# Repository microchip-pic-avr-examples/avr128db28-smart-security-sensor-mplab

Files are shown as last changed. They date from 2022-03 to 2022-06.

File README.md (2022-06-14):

<!-- Please do not change this logo with link -->

MCHP (https://www.microchip.com)

# Window Security Sensor with an AVR&reg; DB Microcontroller,  MLX90632 and MLX90392

The objective of this application is to create a window security sensor with room temperature monitoring for a compact smart home solution. The AVR128DB28 microcontroller was selected for this application in order to use [Multi-Voltage I/O (MVIO) peripheral](#) to communicate with the sensors. To implement this solution, an [MLX90632](https://www.melexis.com/en/product/MLX90632) and an [MLX90392 sensor](https://www.melexis.com/en/product/MLX90392) were used.

This application was co-developed with Melexis, a global supplier of microelectronic semiconductor solutions.

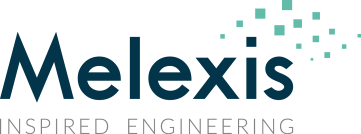
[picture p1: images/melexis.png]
Melexis Logo (https://www.melexis.com/)


## Related Documentation
- [MLX90632 (FIR Thermometer) Homepage](https://www.melexis.com/en/product/MLX90632/Miniature-SMD-Infrared-Thermometer-IC)
  - [MLX90632 Reference Software Library (from Melexis)](https://github.com/melexis/mlx90632-library)
- [MLX90392 (3D Magnetometer) Homepage](https://www.melexis.com/en/product/MLX90392/3D-Magnetometer-micro-power-and-cost-conscious)
- [MVIO Peripheral Homepage](https://www.microchip.com/en-us/products/microcontrollers-and-microprocessors/8-bit-mcus/core-independent-and-analog-peripherals/system-flexibility/mvio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)
- [AVR128DB28 Device Homepage](https://www.microchip.com/wwwproducts/en/AVR128DB28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)

## Software Used

- [MPLAB&reg; X IDE v6.0.0 or newer](https://www.microchip.com/en-us/tools-resources/develop/mplab-x-ide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)
- [MPLAB XC8 v2.36 or newer](https://www.microchip.com/en-us/tools-resources/develop/mplab-xc-compilers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)
- [AVR-Dx_DFP v2.0.151](https://packs.download.microchip.com/)  
- Bluetooth&reg; Smart Data App by Microchip
  - [For iOS](https://apps.apple.com/us/app/bluetooth-smart-data/id1004033562)
  - [For Android](https://play.google.com/store/apps/details?id=com.microchip.bluetooth.data&hl=en_US&gl=US)

## Hardware Used

Please consult the Bill of Materials (BOM) in the PCB documentation.

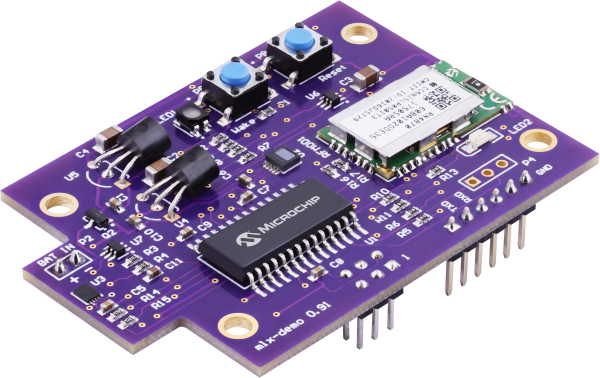
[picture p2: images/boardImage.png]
Board Image


## New in Version 1.1

- Added Range Check
  - Range check allows the demo to also verify the range of X, Y, and Z magnitudes to ensure the magnet is in the correct place. This feature increases the sensitivity of the monitoring. This feature can be disabled in *windowAlarm_config.h* by commenting out `MAGNETOMETER_RANGE_CHECK`.
- Improved Power Efficiency
  - Peripherals are switched off when not needed.
  - Turned off a few missed I/O buffers.
  - Disabled CMP Interrupt in low-power mode if Temperature Monitoring in Sleep is disabled.
  - Magnetometer is now tied to the timing of the microcontroller, which guarantees no missed samples and allows the magnetometer to enter the idle state between cycles.
  - Increased PIT cycle time to better match with magnetometer timing. *This increases the alarm response time of the demo by a small amount.*
- EEPROM Improvements
  - Byte 0 of the EEPROM is now a version ID. Upgrading to a new version of the demo should now automatically reset the EEPROM to defaults. (Note: It is still recommended to fully erase the EEPROM before upgrading.)
  - Added max and min for X, Y, and Z vectors for range check.
  - Using the command `RESET` will now clear the marker for the alarm calibration, forcing a recalibration to occur, **even if power cycled**.
  - Added `EEPROM.md` as documentation about the structure of the EEPROM.
- Bug Fixes

## Table of Contents

- [Estimated Power Consumption](#estimated-power-consumption)
  - [Active Modes (Paired)](#active-modes--paired-)
  - [Slow (30s) Update Rate](#slow--30s--update-rate)
  - [Normal (15s) Update Rate](#normal--15s--update-rate)
  - [Fast (3s) Update Rate](#fast--3s--update-rate)
- [Window Alarm Sensing](#window-alarm-sensing)
  - [The Advantage of a Magnetometer](#the-advantage-of-a-magnetometer)
  - [Calibrating the Magnetometer](#calibrating-the-magnetometer)
    - [Step 1 - Zero Calibration](#step-1---zero-calibration)
    - [Step 2 - Data Normalization](#step-2---data-normalization)
    - [Step 3 - Threshold Set](#step-3---threshold-set)
    - [Step 4 - Return to Closed](#step-4---return-to-closed)
- [Temperature Measurements](#temperature-measurements)
  - [Timing](#timing)
  - [Constant Caching](#constant-caching)
- [Advanced Features](#advanced-features)
  - [Safe Mode](#safe-mode)
- [Operating the Demo](#operating-the-demo)
- [User Commands](#user-commands)

## Estimated Power Consumption

Important: **These values are provided for reference only.** Data collected from 1 unit on the bench. Values were rounded to the nearest &micro;A.

Values were captured with the system powered from a DC power supply at 4.5V through a calibrated precision digital multimeter (with a sampling rate of 10 ksps - 1,000,000 samples per run).

Update rates determine how often new temperature measurements are collected and how often system status reported (either via Bluetooth or the flashed LED, depending on the operating mode).

Magnetometer samples at a constant rate in all modes, except calibration mode. In calibration mode, a higher sampling rate is used.

**Note: Characterized with U7 not populated (VBAT measurement switch). This is not expected to affect power consumption significantly.**  

### Active Modes (Paired)
| Operating Mode | Average Current |
| --- | ---
| Active Mode | 3.928 mA
| Calibration Mode | 5.253 mA

Power consumption in active mode is not expected to vary significantly with update rate.

### Slow (30s) Update Rate
| Operating Mode | Average Current |
| --- | ---
| Low-Power Mode (Temp not Monitored)| 149 &micro;A
| Low-Power Mode (Temp Monitored)| 189 &micro;A

### Normal (15s) Update Rate
| Operating Mode | Average Current |
| --- | ---
| Low-Power Mode (Temp not Monitored)| 151 &micro;A
| Low-Power Mode (Temp Monitored)| 222 &micro;A

### Fast (3s) Update Rate
| Operating Mode | Average Current |
| --- | ---
| Low-Power Mode (Temp not Monitored)| 171 &micro;A
| Low-Power Mode (Temp Monitored)| 505 &micro;A

## Window Alarm Sensing

Sensor Version: MLX90392-011 (&plusmn;50 mT version)

### The Advantage of a Magnetometer

One of the most common ways to detect whether a window or door has been opened/closed by an unknown person is to use a magnetic reed switch. When a magnet is placed near the switch, the two contacts inside either open or close. An external alarm circuit can monitor each circuit to know the current state of the system.

While reed switches are simple and easy to use, they come with the drawback that they only have 2 binary states. If an external magnet is placed close to the switch, the field from the added magnet can hold the contacts in position while the window is opened.

A magnetometer avoids this problem by measuring the intensity of the magnetic field. If the intensity changes beyond a set range, then the magnetometer can detect the attempt to bypass the alarm.

### Magnet Selection and Performance

We tried using a few different magnets during development. An inexpensive off-the-shelf security sensor magnet was used during the initial prototyping without issue, but we found that when mounted a real window, it was too sensitive for long-term use. We found that using a stronger magnet significantly improved performance on the real window. (Alternatively, using the more sensitive device variant of the magnetometer may improve performance with weak magnets.)

We suspect the reason for this discrepancy is due to the increased distance between the magnet and the sensor due to mounting + the protective case.

Note: There is a finite magnetic field range that the sensor can measure. If the magnet is too strong for the sensor, the alarm will be triggered and an error code will occur during calibration.

### Calibrating the Magnetometer

Before using the magnetometer in system, it must be calibrated. Small variations in installation and position are more than enough to cause the alarm to trigger. After some internal testing, we found a 4-step calibration routine worked best.

1. Zero Calibration
2. Data Normalization
3. Threshold Set
4. Return to Closed

#### Step 1 - Zero Calibration

User Directions: *Open the window and press the button to start.*  

To zero the sensor, the microcontroller collects a set number of samples from the magnetometer with the magnet on the window in the farthest position from the sensor. After the set number of samples are acquired, the microcontroller computes the (whole number) average from the totals in each dimension and uses this as the offset.

#### Step 2 - Data Normalization

User Directions: *Please close the window and the press the button to continue.*  

The objective of the data normalization to scale each of the 3 axes to be in similar scales to each other. Due to the direction of travel, one of the axes will have a much higher scale than the others.

The calibration algorithm in this step performs a similar action to the [Zero Calibration in Step 1](#step-1---zero-calibration). However, each averaged value is used to compute the scaling factor to compress the values to a signed 8-bit number. If the value is negative, then the scaling factor will be negative.

| Input | Computed Scaling Factor | Normalized Value
| ----- | --- | ---
| 255 | 1 | 127
| -80 | -1 | 80
| -288  | -2 | 72

At the conclusion of this step, the max/min normalized values for each axis starts to be monitored.

**Note: Ideally the values would remain 7-bit, but depending on the placement of the magnetometer, it is possible for the maximum intensity to occur in a slightly different position. The program limits the maximum intensity to 127. For total magnitude, the full normalized value is used.**

#### Step 3 - Threshold Set

User Directions: *Please open the window to the desired threshold, then press the button.*  

In this step, the magnetometer is programmed to the threshold between open and closed. Unlike the reed switch, the user can set how far the window is open before triggering the alarm. Additionally, at the conclusion of this step, the program stores the highest magnitude of the field strength recorded between (the end of) step 2 and 3.

Magnitude<sup>2</sup> = X<sup>2</sup> + Y<sup>2</sup> + Z<sup>2</sup>

The maximum magnitude is used to protect against attempts to tamper with the sensor with another magnet.

When this step completes, the max/min normalized values for each axis will stop being monitored.

#### Step 4 - Return to Closed

User Directions: *Please close the window and press the button to finish.*  

This step validates the calibration while the user closes the window. If the alarm triggers during this, the calibration is considered bad and returns to step 1. If the window is closed and the alarm did not trigger, then the constants are saved to the EEPROM of the microcontroller.

## Temperature Measurements

Sensor: MLX90632

### Timing

The MLX90632 sensor takes 500ms to get one half of a sample (see sensor datasheet), and/or 1s for a full conversion. This demo only uses the full conversion timing. Due to the acquisition time delay, the microcontroller starts the temperature acquisition early to ensure the results are ready when the application prints the status.

### Constant Caching
To improve the start-up time of the application, the factory calibration constants stored on the MLX90632 are converted into the required floating point values and are stored in the microcontroller's EEPROM memory.

On startup, the microcontroller looks at the EEPROM to:

- Match the serial number of the sensor to the value in memory
- Match the XOR of the serial number words

If either of these checks fail, then the memory is considered invalid, and the constants will be reacquired and reprogrammed into EEPROM. Other constants related to the temperature sensor will also be reset.

Constant Caching can be disabled by commenting out the macro `CACHE_CONSTANTS` in **MLX90632.h**. Booting the application in safe mode will also ignore the EEPROM values.

## Advanced Features

### Safe Mode
To enter safe mode:
- Hold the "Wake" button
- Power-up the demo

In safe mode, the application ignores stored values in EEPROM and resets all user settings to the compile-time defaults. Constants for the MLX90632 (temp. sensor) will be reacquired and cached and the magnetometer will need to be recalibrated before use.

**Note: If the application is powered-off before recalibrating the magnetometer, the magnetometer will load the old calibration on the next start-up.**

## Operating the Demo

For ease of demonstrability, an [RN4870 Bluetooth module](https://www.microchip.com/en-us/product/RN4870) was used for wireless communication. In a production setting, we'd recommend switching to a different wireless communication method, like [Sub-GHz Radio](https://www.microchip.com/en-us/products/wireless-connectivity/sub-ghz).

### Pairing

Instructions, System Conditions, and other messages are sent via Bluetooth to the user's smartphone.

1. Open the Microchip Smart Data App
  1. Download links are provided in the [Software Used](#software-used) section.
2. Power-On the Demo Board.
3. Connect to the Bluetooth Device **MCHP-MLX_UXYZ**, where UXYZ is the S/N of the RN4870.
4. After connecting, a status message should appear in the app's terminal window.

### Sending Commands

Commands can be sent to the demo board to get more information or changing operating parameters / user settings.

All commands must be sent in the following format: **!\<Command,Parameter\>!**, with the ! acting as the deliminator. In cases where the parameter is not used (ex: HELP), it should be omitted.

Command Examples:  
**!HELP!** - Prints Help  
**!STU,F!** - Sets Temperature Units to Fahrenheit

Commands are not case-sensitive.

### User Command List

| User Command | Format | Example Use | Description
| --- | --- | --- | ---
| HELP | HELP | HELP | Get help with this demo. (Provides link to this document.)
| DEMO | DEMO | DEMO | Prints information about this demo and the build date/time. Also aliased as INFO.
| USER | USER | USER | Prints current user-defined settings
| CAL | CAL | CAL | Prints current calibration constants (for developers only)
| MAGRAW | MAGRAW | MAGRAW | Requests the next magnetometer result to be displayed on the screen. This usually occurs immediately after sending this command.
| VBAT  | VBAT  | VBAT | Prints current battery voltage. This function will block for 50 ms to allow the voltage divider to stabilize before measurement.
| RECAL | RECAL | RECAL | Triggers a new calibration cycle of the demo.
| STATUS | STATUS | STATUS | Prints the current system status.
| RESET | RESET | RESET | Resets the user settings to the defaults. The demo will also be reset to calibration mode.
| REBOOT | REBOOT | REBOOT | Reboots the microcontroller, but does NOT reset the settings.
| STU  | STU,<C/F/K> | STU,F | Sets the Temperature Unit (Celsius (*default*), Fahrenheit, Kelvin).
| STWH | STWH,\<TEMP\> | STWH,40.1 | Sets the High Temperature Alarm Point. Units are inherited from STU.
| STWL | STWL,\<TEMP\> | STWL,10.0 | Sets the High Temperature Alarm Point. Units are inherited from STU.
| STSR | STSR, \<FAST/NORM/SLOW\> | STSR,FAST | Sets the sampling rate of the temp sensor to 3s, 15s, or 30s intervals.
| PWDWN | PWDWN | PWDWN | Electrically disconnects the Bluetooth radio, stopping communications. Calibration must be valid and alarm is inactive to enter this state. See [Low Power Mode](#low-power-mode) for more information. Also aliased as PWRDWN.
| BTIDLEOFF | BTIDLEOFF,\<TRUE/FALSE\> | BTIDLEOFF,false | Enables (true) or disables (false) idle Bluetooth power-down. If enabled, after 30s where the system is not connected to a device, calibration is OK, and alarm is inactive, the system will auto-switch to [Low Power Mode](#low-power-mode).
| TEMPSLEEP | TEMPSLEEP,\<TRUE/FALSE\> | TEMPSLEEP, true | Enables temp monitoring while in sleep. If enabled, the system will measure the temperature via the FIR sensor. If the temperature is out of the expected ranges, the system will wake-up and restart the Bluetooth radio. **This mode will increase power consumption. It is recommended to use NORMAL or SLOW speed update rates to minimize power usage.**

### LED Status Indicator

The RGB LED on the board is used to indicate the following statuses:

Red LED - Alarm Tripped  
Green LED - Alarm Good  
Blue LED - Connected (and able to send) UART to the Smartphone  

If both Red and Green are active, the device is in calibration mode.

### Calibration Mode

To enter calibration mode, press the "Wake" button when NOT in Low Power mode or by sending the command "RECAL".

**Note: If in calibration mode and the board is powered off before completed the calibration previous calibration settings will be used. (Calibration values in progress are NOT stored in EEPROM until the cycle has finished). If the stored values are invalid, the system will request calibration on power being restored.**

### Low Power Mode

For longer battery life, the demo can be placed into Low Power Mode. In this mode, the Bluetooth radio is electrically disconnected from the power-supply. If the alarm is triggered in low power mode, the microcontroller will restart the Bluetooth module and wake-up. While in low power mode, commands from the user are not accepted. **On startup, the device does NOT start in Low Power Mode.**

To enter Low Power Mode, send the "PWDWN" command while the calibration is valid and the alarm is inactive.   
To exit Low Power Mode, press the Cal. button on the demo.

Note: Debug UART will remain active in Low Power Mode.

### Debug UART

A second UART is used on the device to print errors and technical information. A standard off-the-shelf USB-UART bridge can be connected to this pin header to view this output. Debug UART remains active in all modes, including Low Power Mode.

UART Settings:
- 115,200 Baud
- 8 bits, no parity, 1 stop bit
- Transmit Only (receiver not enabled)

## Summary

This demo has shown how MVIO can be used to interface with sensors that run at a different voltage level than the rest of the device. Special thanks again to Melexis for development assistance with this demo.

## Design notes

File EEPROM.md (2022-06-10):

# Internal EEPROM Structure and Mapping

This file is a reference for the structure of the Microcontroller's EEPROM used by the Smart Window Security Sensor.

## Example of a Functioning EEPROM

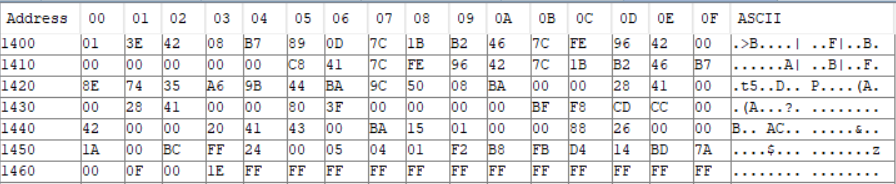
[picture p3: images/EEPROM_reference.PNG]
Reference EEPROM


## Memory Mapping

Without Angle Ranges: 0x1400 to 0x1464  
With Angle Range: 0x1400 to 0x1470

| Address | Variable Name | Type | Length | Description
| --- | --- | ---- | --- | ---
| 0x1400  | MEM_EEPROM_LAYOUT_VERSION_ID | uint8_t | 1 byte | Version ID of the EEPROM Formatting. If the EEPROM is restructured, changing the value of `EEPROM_LAYOUT_VERSION_ID` will cause a mismatch at this location, triggering safe mode on the first power-up after the update.
| 0x1401  | MEM_DEVICE_ID1 | uint16_t | 2 bytes | 1st chunk of the device ID from MLX90632. Used to verify temperature settings.
| 0x1403  | MEM_DEVICE_ID2 | uint16_t | 2 bytes | 2nd chunk of the device ID from MLX90632. Used to verify temperature settings.
| 0x1405  | MEM_DEVICE_ID3 | uint16_t | 2 bytes | 3rd chunk of the device ID from MLX90632. Used to verify temperature settings.
| 0x1407 | MEM_P_R | float | 4 bytes | Cached constant `P_R` from MLX90632.
| 0x140B | MEM_P_G | float | 4 bytes | Cached constant `P_G` from MLX90632.
| 0x140F | MEM_P_T | float | 4 bytes | Cached constant `P_T` from MLX90632.
| 0x1413 | MEM_P_O | float | 4 bytes | Cached constant `P_O` from MLX90632.
| 0x1417 | MEM_EA | float | 4 bytes | Cached constant `EA` from MLX90632.
| 0x141B | MEM_EB | float | 4 bytes | Cached constant `EB` from MLX90632.
| 0x141F | MEM_FA | float | 4 bytes | Cached constant `FA` from MLX90632.
| 0x1423 | MEM_FB | float | 4 bytes | Cached constant `FB` from MLX90632.
| 0x1427 | MEM_GA | float | 4 bytes | Cached constant `GA` from MLX90632.
| 0x142B | MEM_GB | float | 4 bytes | Cached constant `GB` from MLX90632.
| 0x142F | MEM_KA | float | 4 bytes | Cached constant `KA` from MLX90632.
| 0x1433 | MEM_HA | float | 4 bytes | Cached constant `HA` from MLX90632.
| 0x1437 | MEM_HB | float | 4 bytes | Cached constant `HB` from MLX90632.
| 0x143B | MEM_VALIDATE | uint16_t | 2 bytes | XOR of the MLX90632 device IDs. Used to verify temperature settings.
| 0x143D | TEMP_WARNING_HIGH_LOCATION | float | 4 bytes | User-defined high temperature warning level. **Stored in Celsius, converted to other units at runtime.**
| 0x1441 | TEMP_WARNING_LOW_LOCATION | float | 4 bytes | User-defined low temperature warning level. **Stored in Celsius, converted to other units at runtime.**
| 0x1445 | TEMP_UNIT_LOCATION | char | 1 byte | User-defined temperature unit. Valid values are C, F, or K.
| 0x1446 | TEMP_MONITOR_SLEEP_ENABLE | bool | 1 byte | If set, the temperature is monitored in sleep.
| 0x1447 | MEM_MLX90392_ID | uint8_t | 1 byte | ID of the MLX90392 sensor. Used to verify magnetometer settings.
| 0x1448 | CRACKED_THRESHOLD_V | uint32_t | 4 bytes | Open/closed threshold value for the magnetometer.
| 0x144C | MAX_VALUE_V | uint32_t | 4 bytes | Maximum magnetic field intensity considered valid by the magnetometer.
| 0x1450 | MAGNETOMETER_OFFSET_X | int16_t | 2 bytes | DC offset of the magnetometer when the window is open in the X-axis.
| 0x1452 | MAGNETOMETER_OFFSET_Y | int16_t | 2 bytes | DC offset of the magnetometer when the window is open in the Y-axis.
| 0x1454 | MAGNETOMETER_OFFSET_Z | int16_t | 2 bytes | DC offset of the magnetometer when the window is open in the Z-axis.
| 0x1456 | MAGNETOMETER_SCALER_X | int8_t | 1 byte | Normalizing (scaling) factor for the X-axis measurements. See `README.md` for more information.
| 0x1457 | MAGNETOMETER_SCALER_Y | int8_t | 1 byte | Normalizing (scaling) factor for the Y-axis measurements. See `README.md` for more information.
| 0x1458 | MAGNETOMETER_SCALER_Z | int8_t | 1 byte | Normalizing (scaling) factor for the Z-axis measurements. See `README.md` for more information.
| 0x1459 | MAGNETOMETER_MAX_X | int8_t | 1 byte | Max normalized value allowed for X-axis measurements. Exceeding this value will trigger the alarm.
| 0x145A | MAGNETOMETER_MIN_X | int8_t | 1 byte | Min normalized value allowed for X-axis measurements. Values below this will trigger the alarm.
| 0x145B | MAGNETOMETER_MAX_Y | int8_t | 1 byte | Max normalized value allowed for Y-axis measurements. Exceeding this value will trigger the alarm.
| 0x145C | MAGNETOMETER_MIN_Y | int8_t | 1 byte | Min normalized value allowed for Y-axis measurements. Values below this will trigger the alarm.
| 0x145D | MAGNETOMETER_MAX_Z | int8_t | 1 byte | Max normalized value allowed for Z-axis measurements. Exceeding this value will trigger the alarm.
| 0x145E | MAGNETOMETER_MIN_Z | int8_t | 1 byte | Min normalized value allowed for Z-axis measurements. Values below this will trigger the alarm.
| 0x145F | SYSTEM_GOOD_MARKER | uint8_t | 1 byte | Marker to determine if general settings are valid.
| 0x1460 | SYSTEM_UPDATE_PERIOD | uint16_t | 2 bytes | Number of RTC cycles to wait before printing the system status.
| 0x1462 | SYSTEM_BLUETOOTH_IDLE_PERIOD | uint16_t | 2 bytes | Number of RTC cycles to wait before transitioning to low-power mode, if the alarm is OK and Bluetooth is not active.
| 0x1464 | MAGNETOMETER_MIN_XY | int16_t | 2 bytes | Min valid ratio of X/Y. **Not enabled by default.**
| 0x1466 | MAGNETOMETER_MAX_XY | int16_t | 2 bytes | Max valid ratio of X/Y. **Not enabled by default.**
| 0x1468 | MAGNETOMETER_MIN_XZ | int16_t | 2 bytes | Min valid ratio of X/Z. **Not enabled by default.**
| 0x146A | MAGNETOMETER_MAX_XZ | int16_t | 2 bytes | Max valid ratio of X/Z. **Not enabled by default.**
| 0x146C | MAGNETOMETER_MIN_YZ | int16_t | 2 bytes | Min valid ratio of Y/Z. **Not enabled by default.**
| 0x146E | MAGNETOMETER_MAX_YZ | int16_t | 2 bytes | Max valid ratio of Y/Z. **Not enabled by default.**

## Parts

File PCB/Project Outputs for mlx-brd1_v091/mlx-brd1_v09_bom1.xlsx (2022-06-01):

Line # | Designator | Quantity | Name | Description | Digi-Key PN | MPN
1 | C1, C5, C6, C7, C8, C9, C10 | 7 | 100nF | CAP CER 0.1UF 50V X7R 0603 | 311-3567-1-ND | CC0603KPX7R9BB104
2 | C2, C3, C4 | 3 | 22uF | CAP CER 22UF 10V X5R 1206 | 311-1995-1-ND | CC1206MKX5R6BB226
3 | C11 | 1 | 1uF | Capacitor | 587-1242-1-ND
4 | R1, R3, R4, R12, R16, R17 | 6 | 10k0 | RES 10K OHM 1% 1/8W 0603 | RNCP0603FTD10K0CT-ND | RNCP0603FTD10K0
5 | R5, R6, R7, R8, R9,R10,R11, R13 | 6 | 1k0 | RES 1K OHM 1% 1/8W 0603 | RNCP0603FTD1K00CT-ND | RNCP0603FTD1K00
6 | R14, R15 | 2 | 2k2 | RES 2.21K OHM 1% 1/8W 0603 | RNCP0603FTD2K21CT-ND | RNCP0603FTD2K21
7 | RFMOD1 | 1 | RN4870 BTLE MODULE | Bluetooth LE Module | 150-RN4870-V/RM140-ND | 150-RN4870-V/RM140
8 | SP1, SP2, SP3 | 3 | 45x60mil solder pad | solder pad | n/a | n/a
9 | PB-SW1, PB-SW2 | 2 | PB Switch | SWITCH TACTILE SPST-NO 0.05A 12V | CKN9112CT-ND | PTS645SM43SMTR92LFS
10 | LED1 | 1 | RGB LED | Red, Green, Blue _RGB_ 622nm Red, 530nm Green, 470nm Blue LED Indication - Discrete 1.9V Red, 3V Green, 3V Blue 4-PLCC | CLVBA-FKA-CAEDH8BBB7A363CT-ND | CLVBA-FKA-CAEDH8BBB7A363
11 | LED2 | 1 | Status LED | LED AMBER CLEAR 1206 SMD | 1830-1091-1-ND | IN-S126ATA
12 | P1 | 1 | UDPI HDR | Connector Header Through Hole 6 position 0.100" (2.54mm) | 609-5700-ND | 77313-118-06LF
13 | P2 | 1 | Header 2 | Header, 2-Pin Right Angle | WM19498-ND | 22289020
14 | P3 | 1 | Header 6 | Header, 6-Pin | WM8088-ND | 901200766
15 | P4 | 1 | Header 3 | Header, 3-Pin | WM8073-ND | 901200123
16 | Q2 | 1 | DMP2004K | MOSFET P-CH 20V 600MA SOT23-3 | DMP2004KDICT-ND | DMP2004K-7
17 | U1 | 1 | AVR128DB28 | IC MCU 8BIT 128KB FLASH 28SOIC | 150-AVR128DB28T-I/SOCT-ND | AVR128DB28T-I/SO
18 | U2 | 1 | MLX90632 |  | n/a
19 | U3 | 1 | MLX90392 |  | n/a
20 | U4 | 1 | MCP1702 - 1.8V | IC REG LINEAR 3.3V 250MA TO92-3 | MCP1702-3302E/TO-ND | MCP1702-3302E/TO
21 | U5 | 1 | MCP1702 - 3.3V | IC REG LINEAR 1.8V 200MA TO92-3 | MCP1702-1802E/TO-ND | MCP1702-1802E/TO
22 | U6, U7 | 2 | MIC94095YC6 | IC PWR SWITCH P-CHAN 1:1 SC70-6 | 576-3494-1-ND | 576-3494-1-ND

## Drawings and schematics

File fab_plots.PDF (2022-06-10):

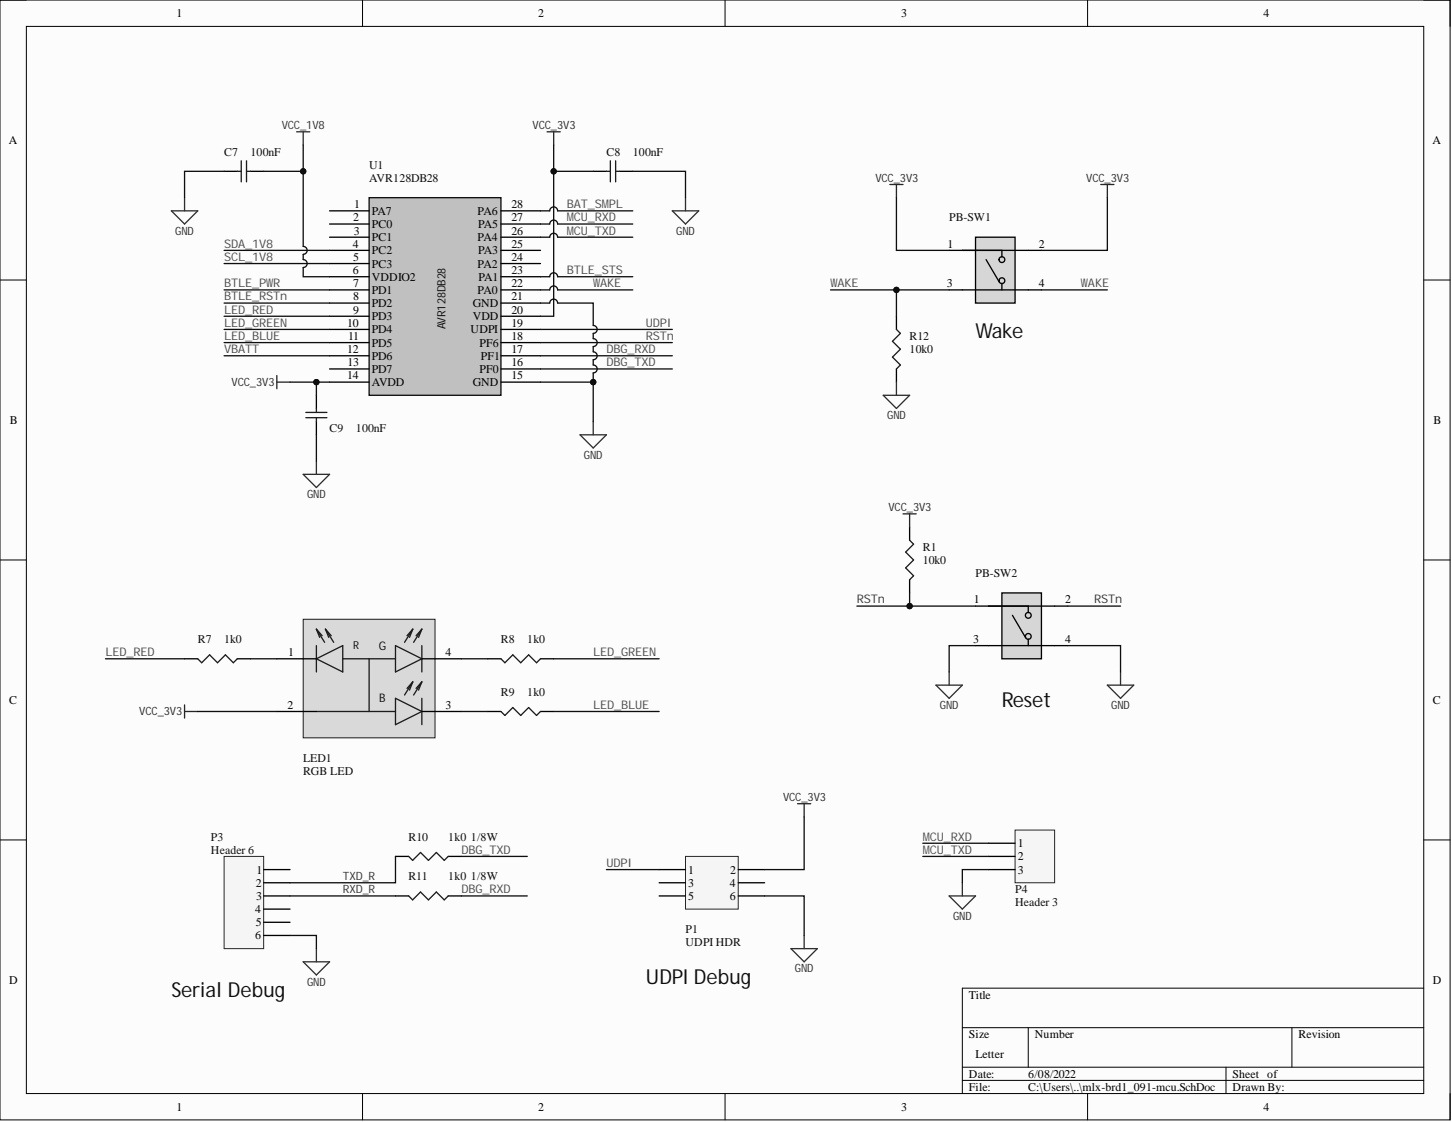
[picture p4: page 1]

PC0 2 | MCU_RXD
PC1 3 | MCU_TXD
PC2 4 | BTLE_STS

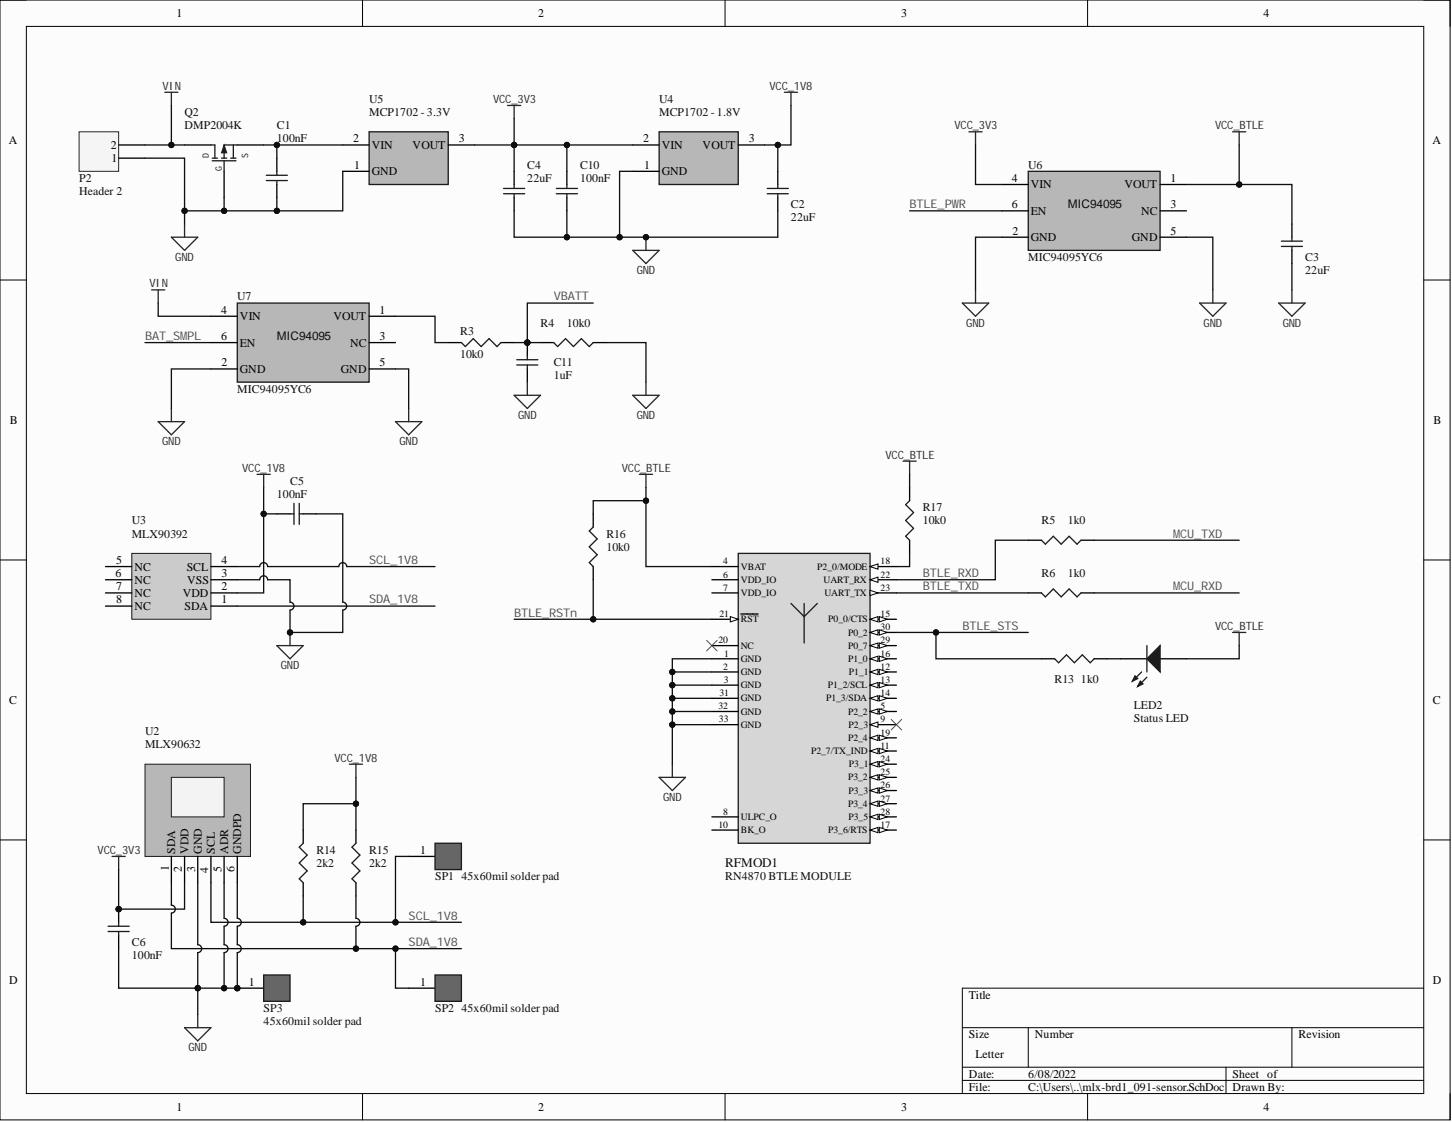
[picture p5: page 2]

SCL_1V8

SDA_1V8

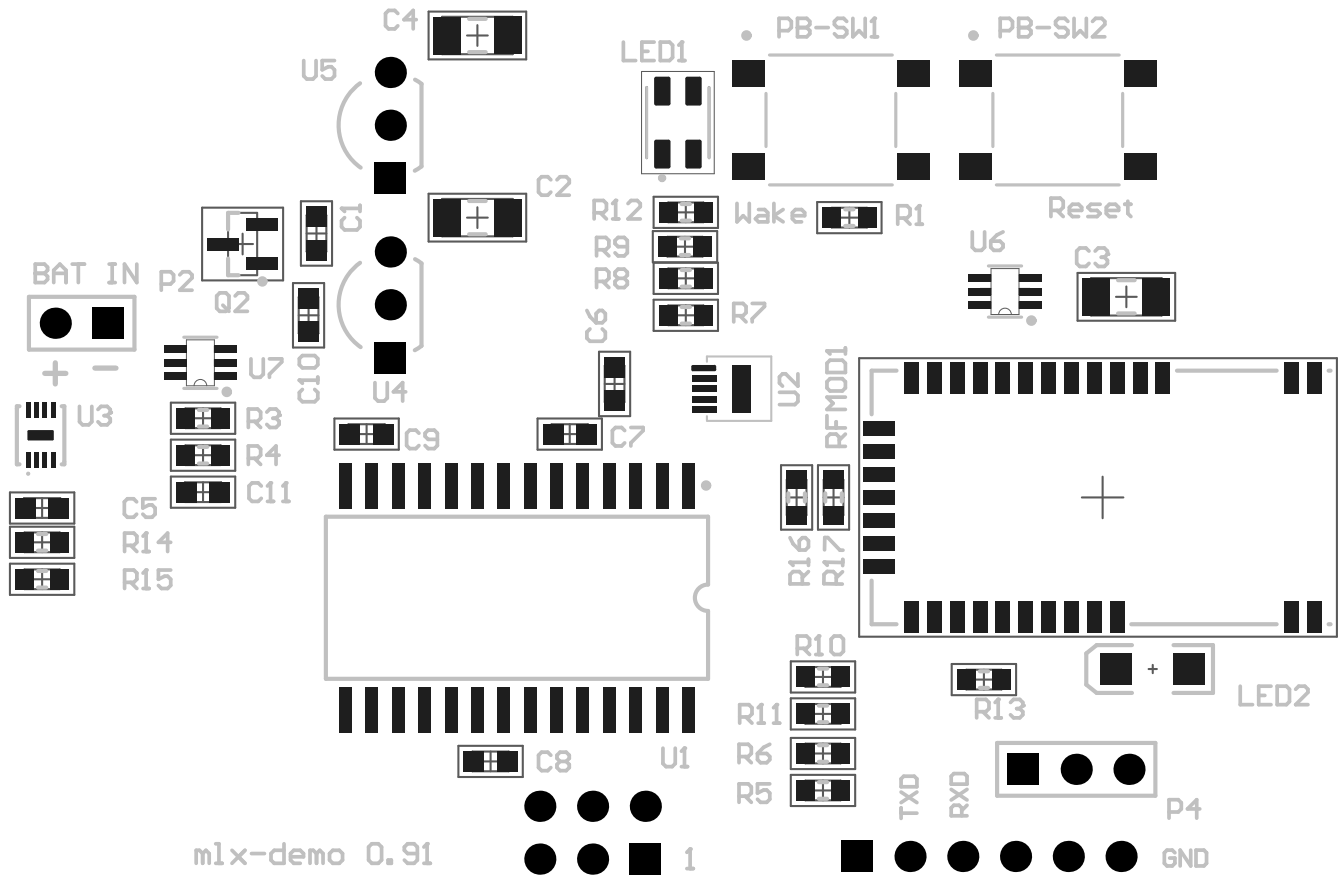
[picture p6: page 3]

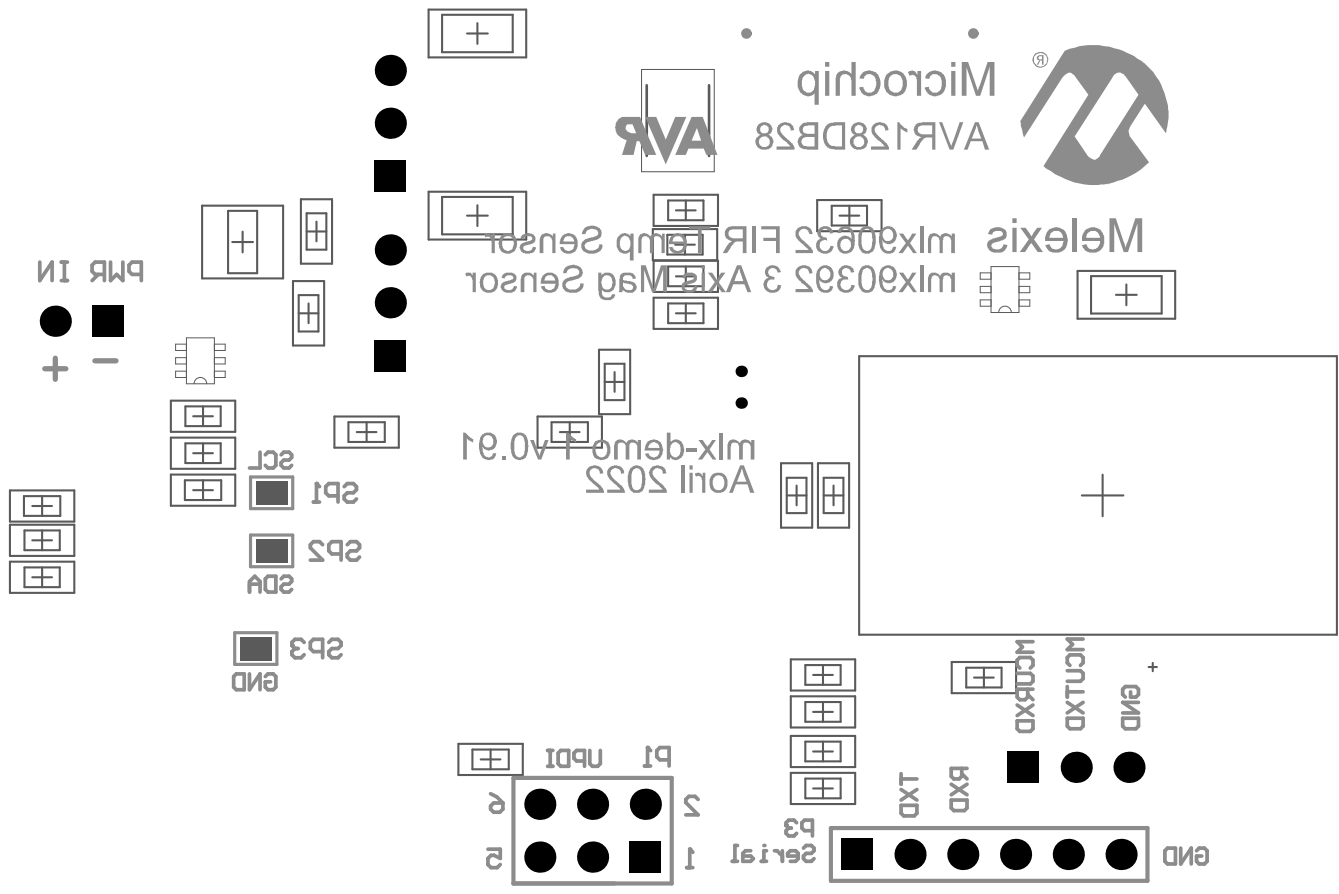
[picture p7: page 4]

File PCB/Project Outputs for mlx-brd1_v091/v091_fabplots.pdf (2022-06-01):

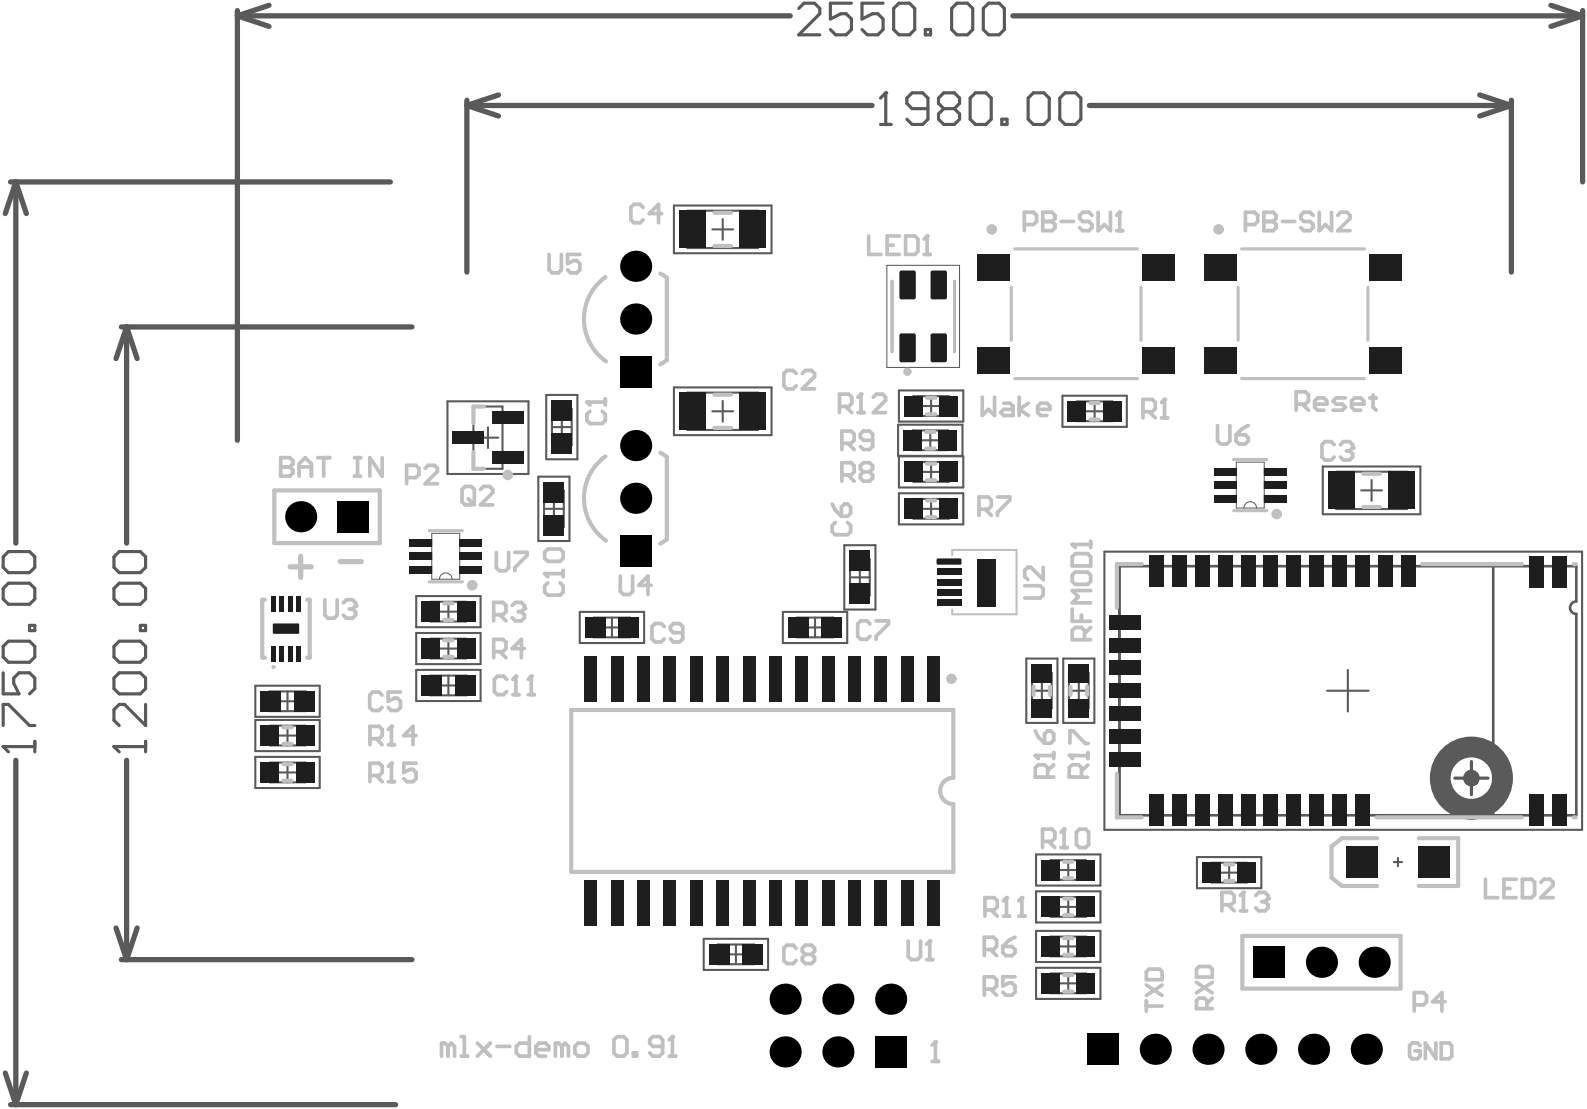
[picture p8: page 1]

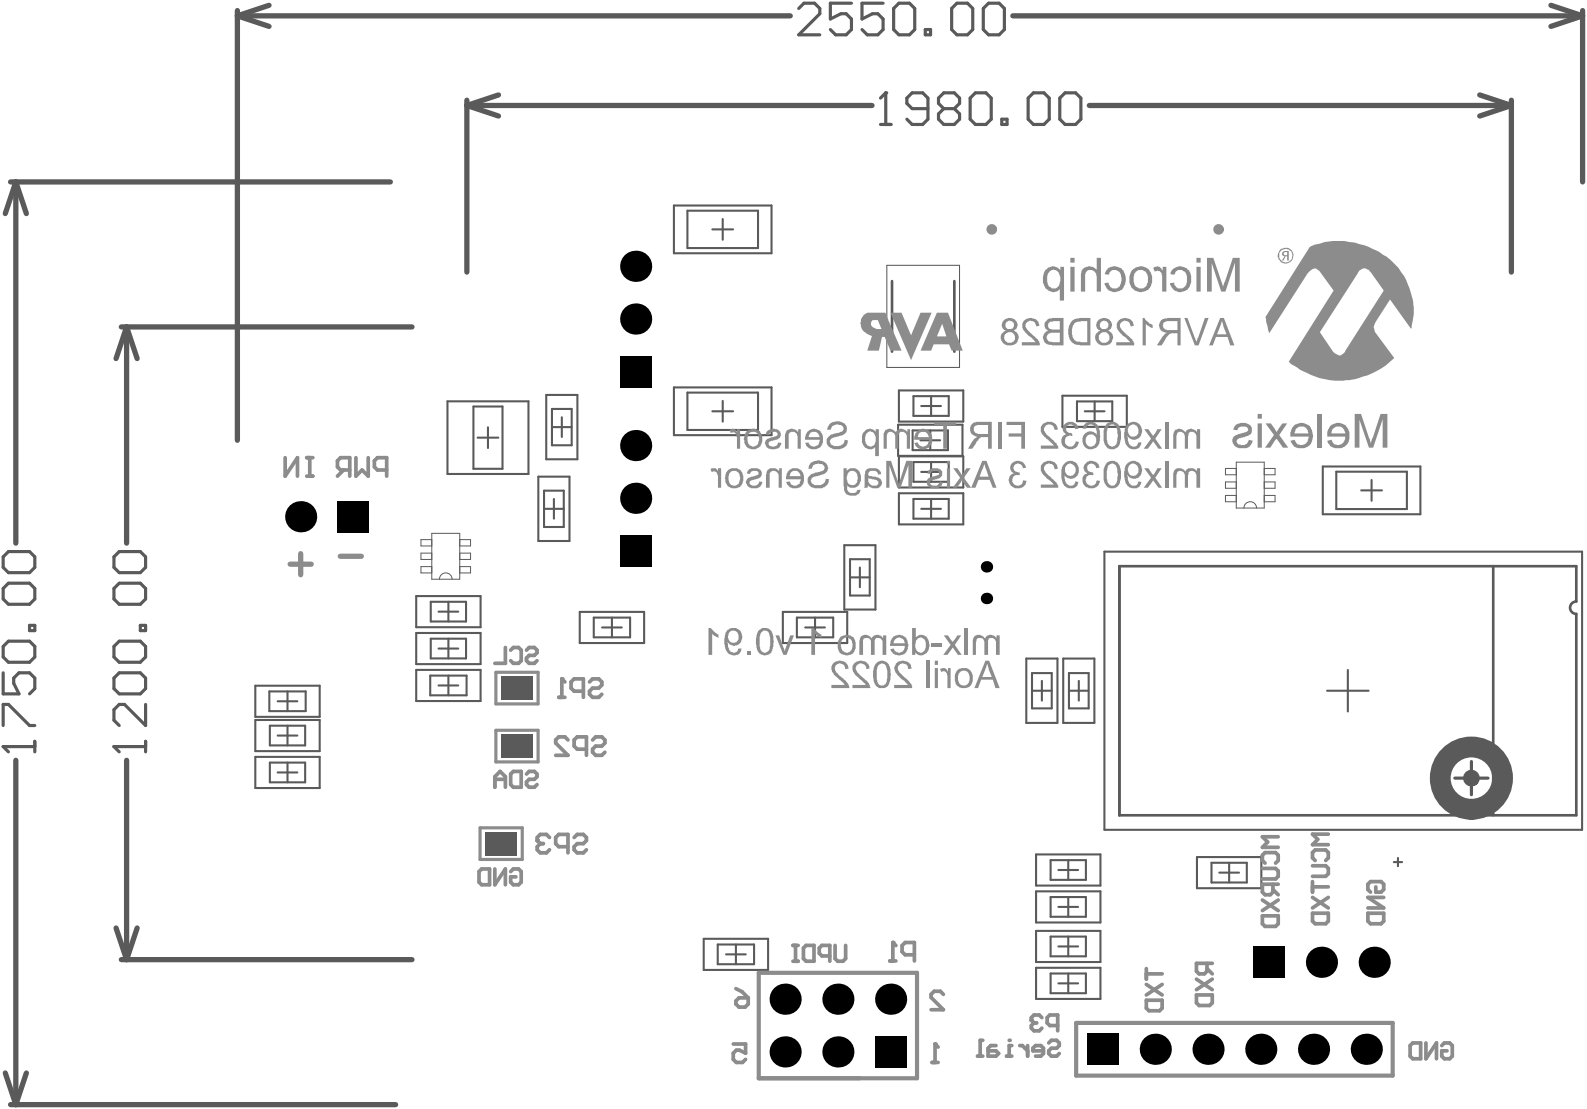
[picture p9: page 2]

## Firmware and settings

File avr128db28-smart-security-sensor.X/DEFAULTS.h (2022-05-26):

/*
© [2022] Microchip Technology Inc. and its subsidiaries.

    Subject to your compliance with these terms, you may use Microchip 
    software and any derivatives exclusively with Microchip products. 
    You are responsible for complying with 3rd party license terms  
    applicable to your use of 3rd party software (including open source  
    software) that may accompany Microchip software. SOFTWARE IS ?AS IS.? 
    NO WARRANTIES, WHETHER EXPRESS, IMPLIED OR STATUTORY, APPLY TO THIS 
    SOFTWARE, INCLUDING ANY IMPLIED WARRANTIES OF NON-INFRINGEMENT,  
    MERCHANTABILITY, OR FITNESS FOR A PARTICULAR PURPOSE. IN NO EVENT 
    WILL MICROCHIP BE LIABLE FOR ANY INDIRECT, SPECIAL, PUNITIVE, 
    INCIDENTAL OR CONSEQUENTIAL LOSS, DAMAGE, COST OR EXPENSE OF ANY 
    KIND WHATSOEVER RELATED TO THE SOFTWARE, HOWEVER CAUSED, EVEN IF 
    MICROCHIP HAS BEEN ADVISED OF THE POSSIBILITY OR THE DAMAGES ARE 
    FORESEEABLE. TO THE FULLEST EXTENT ALLOWED BY LAW, MICROCHIP?S 
    TOTAL LIABILITY ON ALL CLAIMS RELATED TO THE SOFTWARE WILL NOT 
    EXCEED AMOUNT OF FEES, IF ANY, YOU PAID DIRECTLY TO MICROCHIP FOR 
    THIS SOFTWARE.
*/

#ifndef DEFAULTS_H
#define	DEFAULTS_H

#ifdef	__cplusplus
extern "C" {
#endif

//Default Result Rate (15s))
#define DEFAULT_RTC_PERIOD 0x0F00
        
//Default Bluetooth Idle Time (30s)
#define DEFAULT_BLUETOOTH_IDLE_PERIOD 0x1E00
    
//Default Temp Unit
#define DEFAULT_TEMP_UNIT 'C'
    
//Default High Temp Warning (90F/32.2C). Value must be in C
#define DEFAULT_TEMP_WARNING_H 32.2

//Default High Temp Warning (50F/10C). Value must be in C
#define DEFAULT_TEMP_WARNING_L 10.0

#ifdef	__cplusplus
}
#endif

#endif	/* DEFAULTS_H */

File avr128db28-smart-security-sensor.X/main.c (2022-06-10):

/*
© [2022] Microchip Technology Inc. and its subsidiaries.

    Subject to your compliance with these terms, you may use Microchip 
    software and any derivatives exclusively with Microchip products. 
    You are responsible for complying with 3rd party license terms  
    applicable to your use of 3rd party software (including open source  
    software) that may accompany Microchip software. SOFTWARE IS ?AS IS.? 
    NO WARRANTIES, WHETHER EXPRESS, IMPLIED OR STATUTORY, APPLY TO THIS 
    SOFTWARE, INCLUDING ANY IMPLIED WARRANTIES OF NON-INFRINGEMENT,  
    MERCHANTABILITY, OR FITNESS FOR A PARTICULAR PURPOSE. IN NO EVENT 
    WILL MICROCHIP BE LIABLE FOR ANY INDIRECT, SPECIAL, PUNITIVE, 
    INCIDENTAL OR CONSEQUENTIAL LOSS, DAMAGE, COST OR EXPENSE OF ANY 
    KIND WHATSOEVER RELATED TO THE SOFTWARE, HOWEVER CAUSED, EVEN IF 
    MICROCHIP HAS BEEN ADVISED OF THE POSSIBILITY OR THE DAMAGES ARE 
    FORESEEABLE. TO THE FULLEST EXTENT ALLOWED BY LAW, MICROCHIP?S 
    TOTAL LIABILITY ON ALL CLAIMS RELATED TO THE SOFTWARE WILL NOT 
    EXCEED AMOUNT OF FEES, IF ANY, YOU PAID DIRECTLY TO MICROCHIP FOR 
    THIS SOFTWARE.
*/

#include <avr/io.h>
#include <avr/interrupt.h>

#include <stdint.h>
#include <stdbool.h>
#include <avr/eeprom.h>

#include "GPIO.h"

#include "windowAlarm.h"
#include "tempMonitor.h"

#include "RN4870.h"
#include "RN4870_RX.h"

#include "usart2.h"
#include "usart0.h"

#include "TWI0_host.h"

#include "MVIO.h"
#include "system.h"
#include "TCB0_oneShot.h"
#include "RTC.h"
#include "printUtility.h"
#include "demo.h"
#include "TCA0.h"
#include "LEDcontrol.h"
#include "Bluetooth_Timeout_Timer.h"
#include "Welcome_Timer.h"
#include "EEPROM_Locations.h"

#include "MLX90392.h"
#include "MLX90632.h"

//Prints results when not in low-power mode
void normalPrint(void)
{   
    //Update LED State
    DEMO_setAlarmLEDs();
    
    //Check to see if the welcome message should be sent
    if (welcomeTimer_hasTriggered())
    {
        RN4870_sendStringToUser("Welcome to the Microchip Security Sensor Demo!\r\n");
               
        //Disable Welcome Timer
        welcomeTimer_stop();
        RTC_clearOVFTrigger();
        
        //If ready to print results
        if (windowAlarm_getResultStatus())
        {
            windowAlarm_printResults();
        }
        
        if (tempMonitor_getResultStatus())
        {
            tempMonitor_printResults();
        }
        
        //Reset the RTC to remove sampling glitch
        RTC_reset();
        return;
    }
    else if ((welcomeTimer_isRunning()) || (!RN4870_isConnected()))
    {
        //If waiting for welcome or Bluetooth is not connected...
        return;
    }
    
    if (windowAlarm_getResultStatus())
    {
        windowAlarm_printResults();
    }
    else if (RTC_isOVFTriggered())
    {
        RTC_clearOVFTrigger();
        
        windowAlarm_printResults();
        if (windowAlarm_isCalGood())
        {
            //If not calibrating...
            tempMonitor_printResults();
        }
    }
}

//Updates display in low power mode
//LEDs are on for ~1s 
void lowPowerLEDPrint(void)
{
    if (RTC_isOVFTriggered())
    {
        RTC_clearOVFTrigger();
        
        //Update LED states
        DEMO_setAlarmLEDs();
    }
    else
    {
        //Shutoff LEDs
        LED_turnOffGreen();
        LED_turnOffRed();
    }
}

int main(void)
{    
    //Init System / Core Peripherals
    System_initDevice();
    
    //Init Peripherals and IO
    System_initPeripherals();
    
    //Attach Callback Function for USART0
    USART0_setRXCallback(&RN4870RX_loadCharacter);
    
    //Configure Callback for User Commands
    RN4870_setUserEventHandler(&DEMO_handleUserCommands);
    
    //Setup ISR Callback for RTC
    RTC_setCMPCallback(&tempMonitor_requestConversion);
    
    //This boolean is used to determine if reset to defaults is required
    bool safeStart = WAKE_GetValue();
            
    //If EEPROM versions don't match, clear all settings
    if (EEPROM_LAYOUT_VERSION_ID != eeprom_read_byte(MEM_EEPROM_LAYOUT_VERSION_ID))
    {   
        //Force Safestart
        safeStart = true;
        
        //Update Value
        eeprom_write_byte((uint8_t*) MEM_EEPROM_LAYOUT_VERSION_ID, EEPROM_LAYOUT_VERSION_ID);
        
        //Erases the calibration for window alarm, forcing a recal to occur, even if power-cycled.
        windowAlarm_eraseCalibration();
    }
    
    //Init User Settings
    DEMO_init(safeStart);
    
    //Init State Machines
    windowAlarm_init(safeStart);    
    tempMonitor_init(safeStart);
    
    //Start Interrupts
    sei();
    
    //Configure RN4870
    RN4870_init();
    
    //Set Starting Time of BLE Auto-Off Timer
    BLE_SW_Timer_setCurrentTime();
               
    while(1)
    {        
        //Clear the Watchdog Timer
        asm("WDR");
                                                
        //Check for Events
        RN4870_processEvents();
                
        //If in sleep, always run the FSM loops
        //If not, then only run them once per PIT trigger
        if ((RN4870_canSleep()) || ((!RN4870_canSleep()) && (RTC_isPITTriggered())))
        {
            RTC_clearPITTriggered();
            
            //Run the magnetometer state machine
            windowAlarm_FSM();

            //If the calibration for the window alarm is OK AND
            //Not in sleep mode (or Run in Sleep is set)
            if ((windowAlarm_isCalGood()) && ((!RN4870_canSleep()) || tempMonitor_getRunInSleep()))
            {
                //Run the thermometer state machine
                tempMonitor_FSM();
            }
        }
        
        //Magnetometer Alarm

        if (RN4870_canSleep())
        {
            //If we can sleep (ie: BLE is OFF)...
            
            //Update LED states, if applicable
            lowPowerLEDPrint();
            
            if (windowAlarm_isAlarmOK() && tempMonitor_isTempNormal())
            {          
                //Alarm OK - continue sleep

                //Trigger next magnetometer sample
                MLX90392_setOperatingMode(SINGLE);
                
                TCB0_disable();
                TWI0_disable();
                
                //Disable Debug UART
                USART2_disableTX();
                
                asm("SLEEP");
                asm("NOP");
                
                //Re-enable Debug UART
                USART2_enableTX();
                
                TCB0_enable();
                TWI0_enable();
            }
            else
            {
                //Alarm tripped - wake-up
                RN4870_powerUp();                
            }         
        }
        else
        {
            //Can't enter sleep, print normally
            normalPrint();
            
            //Add RTC Changes to SW Timers
            BLE_SW_Timer_addTime();
            welcomeTimer_addTime();
            
            //If Timer triggered
            if ((BLE_SW_Timer_hasTriggered()) && (windowAlarm_isAlarmOK()) &&
                    (windowAlarm_isCalGood()) && (!RN4870_isConnected()))
            {
                USB_sendStringWithEndline("Bluetooth Idle timeout has occurred. Switching to low power mode.");
                RN4870_powerDown();
            }
        }
    }    
}

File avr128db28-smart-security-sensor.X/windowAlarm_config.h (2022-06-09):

/*
© [2022] Microchip Technology Inc. and its subsidiaries.

    Subject to your compliance with these terms, you may use Microchip 
    software and any derivatives exclusively with Microchip products. 
    You are responsible for complying with 3rd party license terms  
    applicable to your use of 3rd party software (including open source  
    software) that may accompany Microchip software. SOFTWARE IS ?AS IS.? 
    NO WARRANTIES, WHETHER EXPRESS, IMPLIED OR STATUTORY, APPLY TO THIS 
    SOFTWARE, INCLUDING ANY IMPLIED WARRANTIES OF NON-INFRINGEMENT,  
    MERCHANTABILITY, OR FITNESS FOR A PARTICULAR PURPOSE. IN NO EVENT 
    WILL MICROCHIP BE LIABLE FOR ANY INDIRECT, SPECIAL, PUNITIVE, 
    INCIDENTAL OR CONSEQUENTIAL LOSS, DAMAGE, COST OR EXPENSE OF ANY 
    KIND WHATSOEVER RELATED TO THE SOFTWARE, HOWEVER CAUSED, EVEN IF 
    MICROCHIP HAS BEEN ADVISED OF THE POSSIBILITY OR THE DAMAGES ARE 
    FORESEEABLE. TO THE FULLEST EXTENT ALLOWED BY LAW, MICROCHIP?S 
    TOTAL LIABILITY ON ALL CLAIMS RELATED TO THE SOFTWARE WILL NOT 
    EXCEED AMOUNT OF FEES, IF ANY, YOU PAID DIRECTLY TO MICROCHIP FOR 
    THIS SOFTWARE.
*/

#ifndef WINDOWALARM_CONFIG_H
#define	WINDOWALARM_CONFIG_H

#include "MLX90392.h"


#ifdef	__cplusplus
extern "C" {
#endif

//Sets the default sample rate in calibration mode
#define MAGNETOMETER_CAL_SAMPLE_RATE CONT_200HZ

//Sets the sample rate when running normally
#define MAGNETOMETER_ACTIVE_SAMPLE_RATE CONT_10HZ
    
//If defined, this will print values in CSV format
//#define MAGNETOMETER_PRINT_CSV
    
//If defined, this will print a formatted string containing the magnetometer raw values
//#define MAGNETOMETER_RAW_VALUE_PRINT
             
//If defined, this will print extra debug info
//#define MAGNETOMETER_DEBUG_PRINT
        
//How many cycles of the PIT to run before reprinting magnetometer error
#define MAGNETOMETER_ERROR_DELAY 1250

//How many samples to use for MAX / MIN comparisons
#define MAGNETOMETER_CALIBRATION_SAMPLES 1024
    
//How many right-shifts for the acquired average
#define MAGNETOMETER_RSHIFT_SAMPLE_COUNT 10
        
//Defines the number of events to trigger the alarm
#define MAGNETOMETER_ALARM_TRIGGER 10
    
//Defines the highest range for the alarm
#define MAGNETOMETER_ALARM_TRIGGER_MAX 20

//Defines the number of cycles to run between printing alarm status. Ignored at trigger thrshold
#define MAGNETOMETER_ALARM_PRINT_RATE 20
    
//Defines the vector noise margin
#define MAGNETOMETER_NOISE_MARGIN 40
    
//Comment out this define to disable
//Magnitude Tolerance for Alarm (1 + (% Value))
#define MAGNETOMETER_VECTOR_TOLERANCE 0.15

//If defined, the angles of the magnetometer will be computed and used to monitor for tampering.
//#define MAGNETOMETER_ANGLE_CHECK
    
//If defined, magnetometer will check to see if X, Y, and Z are within limits
#define MAGNETOMETER_RANGE_CHECK 
    
//Pre-Scaler for Computing Angles (X/Y, X/Z, Y/Z)
#define MAGNETOMETER_ANGLE_SCALE 100
    
//Comment out this define to disable
//Angular Position Tolerance for Alarm (# of bits +/- this value)
#define MAGNETOMETER_ANGLE_TOLERANCE 5

#ifdef	__cplusplus
}
#endif

#endif	/* WINDOWALARM_CONFIG_H */

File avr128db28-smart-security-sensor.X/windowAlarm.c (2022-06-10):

#include "GPIO.h"

#include <stdint.h>
#include <stdbool.h>
#include <math.h>
#include <stdio.h>
#include <avr/eeprom.h>

#include "printUtility.h"
#include "windowAlarm.h"
#include "windowAlarm_config.h"
#include "MLX90392.h"
#include "EEPROM_Locations.h"
#include "MVIO.h"
#include "windowAlarm_messages.h"
#include "RN4870.h"
#include "TWI0_host.h"
#include "LEDcontrol.h"
#include "Bluetooth_Timeout_Timer.h"

//Enumeration for the Measurement State Machine
typedef enum {
MAGNETOMETER_START = 0, MAGNETOMETER_WAIT, MAGNETOMETER_ERROR, 
        MAGNETOMETER_REINIT_WAIT, MAGNETOMETER_REINIT
} MagentometerMeasState;

//Enumeration for Calibration State Machine
typedef enum{
    CAL_BAD = 0, CAL_INIT, CAL_OPEN_WAIT, CAL_OPEN, CAL_CLOSED_WAIT, CAL_CLOSED, 
            CAL_CRACKED_WAIT, CAL_CRACKED_ERR, CAL_CRACKED, CAL_CLOSED_FINAL_WAIT, 
            CAL_DEINIT, CAL_GOOD
} MagnetometerCalibrationState;

//Enumeration for the Result Printing State Machine
typedef enum{
    WINDOW_CLOSED = 0, WINDOW_CRACKED, WINDOW_OPEN, INVALID
} MagnetometerResultState;

//Calibration Status
static MagnetometerCalibrationState calState = CAL_BAD;
static MagnetometerResultState prevResultState = INVALID;

//State Machine Variables
static volatile MagentometerMeasState magState = MAGNETOMETER_START;
//static volatile uint16_t magCounter = MAGNETOMETER_ERROR_DELAY;

//If set, the next data will be printed to the RN4870
static bool requestPrint = false;

//Alarm Parameters
static uint32_t crackedV, maxV;
static int16_t offsetX = 0, offsetY = 0, offsetZ = 0;
static uint8_t scaleX = 1, scaleY = 1, scaleZ = 1;

#ifdef MAGNETOMETER_RANGE_CHECK
static int8_t maxX, minX, maxY, minY, maxZ, minZ;
#endif


//Angle Ranges
#ifdef MAGNETOMETER_ANGLE_CHECK
static int16_t minXY, maxXY, minXZ, maxXZ, minYZ, maxYZ;
#endif

//Result Print, Current Button State, Last Button State
static bool alarmResultsReady = false, buttonPressed = false, lastButtonState = false;

//ID of Magnetometer
static uint8_t sensorID = 0x00;

//Alarm Count
static uint8_t alarmState = 0;

uint8_t _windowAlarm_computeScalingFactor(int16_t result)
{
    uint8_t scale = 1;
    
    //Negate Input
    if (result < 0)
    {
        result *= -1;
    }
 
    //While result doesn't fit in an 7-bit number
    while (result > 127)
    {
        result = result >> 1;
        scale++;
    }
    
    return scale;
}

void windowAlarm_updateAngleMaxMin(MLX90392_NormalizedResults8* normResults)
{
#ifdef MAGNETOMETER_ANGLE_CHECK
    if (minXY > normResults->xyAngle)
    {
        minXY = normResults->xyAngle;
    }
    else if (normResults->xyAngle > maxXY)
    {
        maxXY = normResults->xyAngle;
    }

    if (minXZ > normResults->xyAngle)
    {
        minXZ = normResults->xyAngle;
    }
    else if (normResults->xyAngle > maxXZ)
    {
        maxXZ = normResults->xyAngle;
    }

    if (minYZ > normResults->xyAngle)
    {
        minYZ = normResults->xyAngle;
    }
    else if (normResults->xyAngle > maxYZ)
    {
        maxYZ = normResults->xyAngle;
    }
#endif
}

//Starts a calibration sequence, but does NOT interrupt it.
void windowAlarm_requestCalibration(void)
{
    calState = CAL_BAD;
}

//Internal function for setting the trigger thresholds (calibration)
void windowAlarm_runCalibration(MLX90392_RawResult16* rawResult, MLX90392_NormalizedResults8* normResults)
{
    static MagnetometerCalibrationState oldState = CAL_BAD;
    static uint16_t sampleCount = 0;
    static uint8_t weightedAlarmState = 0;
    
    //Update Angle Max and Min
#ifdef MAGNETOMETER_ANGLE_CHECK
    windowAlarm_updateAngleMaxMin(normResults);
#endif
    
    //Monitor field strength, record strongest magnitude
    if (normResults->r2 > maxV)
    {
        maxV = normResults->r2;
    }
    
    //Averages for zeroing
    static int32_t averageX, averageY, averageZ, averageR2;
    
    switch (calState)
    {
        case CAL_BAD:
        {
            //Configure Instructions State Machine
            oldState = CAL_BAD;
                    
            //Advance State Machine
            calState = CAL_INIT;
            
            //Clear Averaging Variables
            averageX = 0;
            averageY = 0;
            averageZ = 0;
            break;
        }
        case CAL_INIT:
        {
            if (MLX90392_setOperatingMode(MAGNETOMETER_CAL_SAMPLE_RATE))
            {                
                calState = CAL_OPEN_WAIT;
                alarmResultsReady = true;
            }
            else
            {
                USB_sendStringWithEndline("[ERR] Failed to change MLX90392 operating mode.");
            }
            break;
        }
        case CAL_OPEN_WAIT:
        {
            if (buttonPressed)
            {
                USB_sendStringWithEndline("Starting open window calibration.");
                RN4870_sendStringToUser("Beginning open window calibration.");
                calState = CAL_OPEN;
                sampleCount = 0;
            }
            break;
        }
        case CAL_OPEN:
        {
            if (windowAlarm_isMagneticOverflow(rawResult))
            {
                RN4870_sendStringToUser("[ERR] Magnetic Field is too strong. Please retry.");
                calState = CAL_OPEN_WAIT;
            }
            
            sampleCount++;
            
            //Accumulate Results
            averageX += rawResult->X_Meas;
            averageY += rawResult->Y_Meas;
            averageZ += rawResult->Z_Meas;
            
            if (sampleCount >= MAGNETOMETER_CALIBRATION_SAMPLES)
            {
                //Compute Average Offset
                offsetX = averageX >> MAGNETOMETER_RSHIFT_SAMPLE_COUNT;
                offsetY = averageY >> MAGNETOMETER_RSHIFT_SAMPLE_COUNT;
                offsetZ = averageZ >> MAGNETOMETER_RSHIFT_SAMPLE_COUNT;
                
                //Print Debug Info
                sprintf(USB_getCharBuffer(), "Zeroing Complete. X_off = %d, Y_off = %d, Z_off= %d\r\n", offsetX, offsetY, offsetZ);
                USB_sendBufferedString();
                
                //Update State
                calState = CAL_CLOSED_WAIT;            
            }
            break;
        }
        case CAL_CLOSED_WAIT:
        {
            if (buttonPressed)
            {             
                USB_sendStringWithEndline("Starting closed window calibration.");
                RN4870_sendStringToUser("Beginning closed window calibration.");
                calState = CAL_CLOSED;
                sampleCount = 0;
            }
            break;
        }
        case CAL_CLOSED:
        {                    
            if (windowAlarm_isMagneticOverflow(rawResult))
            {
                RN4870_sendStringToUser("[ERR] Magnetic Field is too strong. Please retry.");
                calState = CAL_CLOSED_WAIT;
            }
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

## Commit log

2021-11-02 MPAE-13079: Removed OPAMP + DAC. Initial Version of MLX90632 sensor interface
2021-11-11 MPAE-13079: Many bug fixes and improvements. Began to implement magnetometer thresholds
    [EEPROM_Locations.h, MLX90392.h, MLX90632.c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]
2021-12-01 MPAE-13079: Began to rework 3-point calibration algorithm. (Note: not fully implemented yet)
    [MLX90392.h, main.c, system.c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]
2021-12-10 MPAE-13079: Magnetometer Calibration Implemented, Magnetometer EEPROM changes
2022-01-17 MPAE-13079: Modified RX driver
2022-01-28 MPAE-13079: Minor pointer fix
    [usart2.c]
2022-01-31 MPAE-13079: Added temp alarm functionality. Fixed bug in threshold tolerancing. Added check to calibration step 4
    [EEPROM_Locations.h, MLX90392.h, main.c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]
2022-01-31 MPAE-13079: Fixed possible integer overflow in data normalizer. Renamed folder
    [EEPROM_Locations.h, GPIO.c, MLX90392.h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]
2022-02-03 MPAE-13079: RX Receiver v2. Issues with TWI for temp sensor. Investigating.
    [GPIO.c, RN4870.c, demo.c]
2022-02-03 MPAE-13079: Fixed TWI issue (bus was detected as busy when RN4870 reset). Fixed DBG_OUT GPIO
    [GPIO.c, RN4870.c, TWI0_host.c]
2022-02-23 MPAE-13079: Began to implement power switching. Fixed TWI deadlock on MVIO failure.
    [RN4870.c, TWI0_host.c]
2022-03-10 MPAE-13079: Reworked RTC Timings for Temp Sensor. Improved String Handling. Bug Fixes.
    [EEPROM_Locations.h, demo.c, main.c]
2022-03-10 MPAE-13079: Fixed a major Bluetooth bug. Added more commands. Improved consistancy of defaults
    [DEFAULTS.h, RN4870.c, demo.c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]
2022-03-29 MPAE-13079: First commit of code for custom PCB (untested!), Updated README
2022-03-29 MPAE-13079: Fixed issue with USART2.h -> usart2.h
    [main.c, printUtility.c, system.c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]
2022-04-12 MPAE-13079: Tested code for prototype board rev A.
2022-04-12 MPAE-13079: Added power on/off control to BLE
2022-04-12 MPAE-13079: Added ADC Sampling
2022-04-12 MPAE-13079: Added LED PWM Dimming
2022-04-12 MPAE-13079: Metadata fix. Added comment and removed test code
    [RN4870.c, TCA0.h, main.c]
2022-04-12 MPAE-13079: Improved LED behavior. Added LED API to abstract some switching behavior
2022-04-13 MPAE-13079: Fixed bug in LED power off
    [LEDcontrol.c, RN4870.c]
2022-04-14 MPAE-13079: If alarm trips in low power mode, alarm will start BLE immediately. Added power-down checks. Cal. algorithm tweaks
2022-04-14 MPAE-13079: Bluetooth bug fixes. ADC now measures correctly.
    [ADC.c, RN4870.c, demo.c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]
2022-04-16 MPAE-13079: Fixed function names. Added power section to README (to be filled out later)
    [RN4870.c, TCA0.h]
2022-04-22 MPAE-13079: Added option for temp monitoring in sleep. Cleaned up print functions
2022-04-22 MPAE-13079: Cleaned up BLE print function
2022-04-22 MPAE-13079: Added magnetic overflow monitoring
2022-04-22 MPAE-13079: Switched from round() to right-shift for some operations in calibration
2022-04-24 MPAE-13079: Added user settings print function
2022-04-24 MPAE-13079: Decoupled User Instructions from Magnetometer Cycles. Now linked to printResults calls
2022-04-28 MPAE-13079: Modified firmware for board rev 2. Some fixes for the temp sensor
    [ADC.c, DEFAULTS.h, EEPROM_Locations.h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]
2022-04-28 MPAE-13079: Fixed sampling glitch on connection
    [main.c]
2022-05-03 MPAE-13079: Added new power numbers for Rev 1
2022-05-24 MPAE-13079: RN4870 Power Up Fix. Updated BTLE Polarity for v1.1
    [main.c]
2022-05-24 MPAE-13079: Updated README Power Specs.
2022-05-31 MPAE-13079: Added board image
2022-05-31 MPAE-13079: Reduced size of board image
2022-06-01 MPAE-13079: Added PCB files
    [mlx-brd1.GBL, mlx-brd1.GBO, mlx-brd1.GBP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]
2022-06-09 MPAE-14568: Added option for range calibration. Began power hunting. Added EEPROM documentation.
2022-06-10 MPAE-14568: Continued to improve power efficency of demo.
2022-06-10 MPAE-14568: Cleaned-up code. Tweaks for more power. Added change list to README.
2022-06-10 MPAE-14568: Added Schematic PDF
